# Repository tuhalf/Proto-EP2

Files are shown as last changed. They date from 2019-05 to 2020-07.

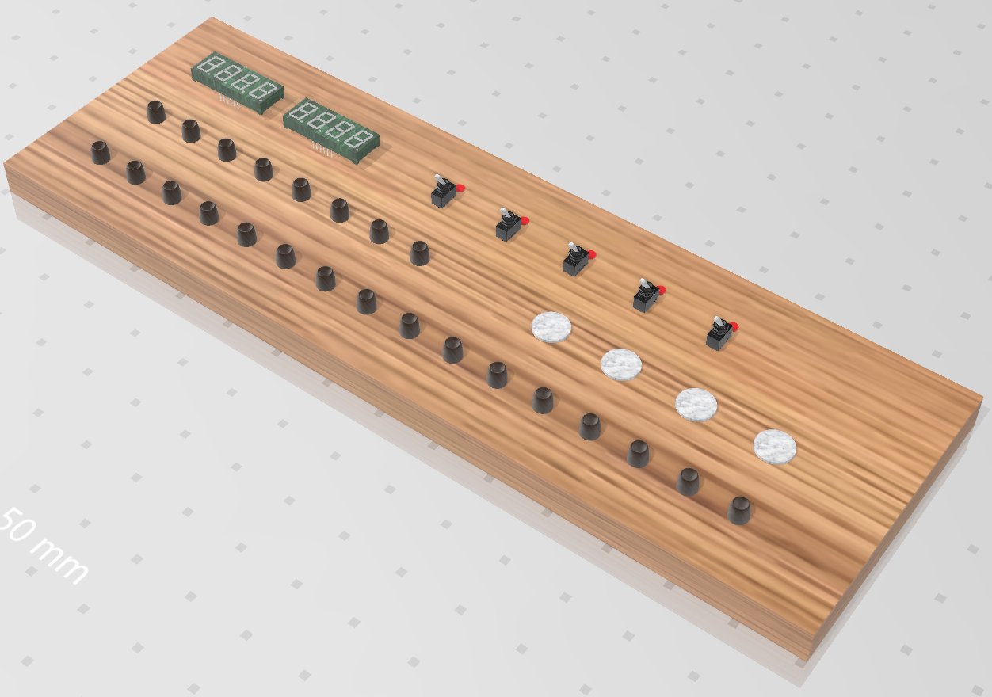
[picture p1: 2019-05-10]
Screenshots/frontPanel.png

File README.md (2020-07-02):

# Proto - Educational Pupose 8-Bit Processor
Made for students, teachers, and any soul who wants to understand how a CPU works. Open Source.

Instruction Sets
 I : Instruction 
{ }: Register 
[ ]: Adress
( ): Condition - Based on registers A and B, takes parameters > or =
______________________________________________________________________
ADD [X]
	Add two numbers that are in A and B registers and write it to X address

SUB [X]- Subtract
	Subtract A from B and write it to X address 

LOAD {X} 
	Load data from next adress to X register 

STORE [X]
	Store data form register A to X adress in RAM 

LWJ {X} [Y] - Load With Jump
	Load data from Y adress to X register

JUMP [X]
	Jump to X adress in RAM

CJ (X) [Y] - Conditional Jump (Carry or Zero)
	If X condition is TRUE, jump to Y adress in RAM
  
LSCR [X] [Y]
	Loads the data stored in X address from RAM to Y address from GPU (Each bit is one pixel)
  
LSCR {X} [Y]
	Loads the data stored in X register to Y address from GPU (Each bit is one pixel)
  
LPNC [X]
	Starts loading the punch card starting from X address
  
HLT
	Halts the system

------------------------------------------------------------------------------------------------------------------------------------

Microcode Explained
bits
0nnnn00000nn00__
1000000000000000    HLT - 1
0100000000000000    REG_READ - 2
0010000000000000    AWRITE - 3	(Connected to ALUWRITE and Or'ed with AWRITE because there are not enough controll bits)
0001000000000000    FL - 4
0000100000000000    ALUWRITE - 5(Connected to RAM_WRITE and Or'ed with AWRITE because there are not enough controll bits)
0000010000000000    ALUSUB - 6
0000001000000000    PC_LE - 7
0000000100000000    PC_LRS - 8
0000000010000000    RAM_LRS - 9
0000000001000000    SLC_ADDR - 10
0000000000100000    RAM_OUT - 11
0000000000010000    INSTREAD - 12
0000000000001000    COUNT - 13
0000000000000100    RAM_AS - 14
0000000000000010    --
0000000000000001    --
01111000 00110000				00------000
----JUMP [X]---- (N-------,XXXXXXXX,XXXXXXXX)	nn100000                        
COUNT						00100000000 - 01111000 00111000
PC_LRS || RAM_OUT				00100000100 - 01111001 00010000
COUNT						00100000010 - 01111000 00111000	
RAM_OUT || PC_LE			        00100000110 - 01111010 00010000
RAM_OUT || INSTREAD				00100000001 - 01111000 00000000
----------------
----LOAD {X}---- (X-------)			                nn010000    
COUNT                                           00010000000 - 01111000 00111000
RAM_OUT || REG_READ                             00010000100 - 00111000 00010000
COUNT                                           00010000010 - 01111000 00111000
RAM_OUT || INSTREAD                             00010000110 - 01111000 00000000
----------------
----ADD [X]---- (N-------,XXXXXXXX,XXXXXXXX)    nn110000
COUNT || RAM_OUT || RAM_LRS || SLC_ADDR         00110000000 - 01111000 11011000
COUNT || RAM_OUT || SLC_ADDR                    00110000100 - 01111000 01011000
RAM_AS || ALUWRITE                              00110000010 - 01110000 00110100
RAM_OUT || INSTREAD                             00110000110 - 01111000 00000000
----------------
----SUB [X]---- (N-------,XXXXXXXX,XXXXXXXX)    nn001000
COUNT || RAM_OUT || RAM_LRS || SLC_ADDR         00001000000 - 01111000 11011000
COUNT || RAM_OUT || SLC_ADDR                    00001000100 - 01111000 01011000
RAM_AS || ALUSUB || ALUWRITE                    00001000010 - 01110100 00110100
RAM_OUT || INSTREAD                             00001000110 - 01111000 00000000
----------------
----STORE [X]---- (N-------,XXXXXXXX,XXXXXXXX)  nn101000
COUNT || RAM_OUT || RAM_LRS || SLC_ADDR         00101000000 - 01111000 11011000
COUNT || RAM_OUT || SLC_ADDR                    00101000100 - 01111000 01011000
RAM_AS || AWRITE                                00101000010 - 01011000 00110100
RAM_OUT || INSTREAD                             00101000110 - 01111000 00000000
-----------------
----LWJ {X} [Y]---- (X-------,YYYYYYYY,YYYYYYYY)nn111000
COUNT || RAM_OUT || RAM_LRS || SLC_ADDR         00111000000 - 01111000 11011000
COUNT || RAM_OUT || SLC_ADDR                    00111000100 - 01111000 01011000
RAM_AS || RAM_OUT || REG_READ                   00111000010 - 00111000 00010100
RAM_OUT || INSTREAD                             00111000110 - 01111000 00000000
-------------------
----CJ (ZERO) [Y]-- (N-1-----,XXXXXXXX,XXXXXXXX)nn001100
COUNT || FL                                     00001100000 - 01101000 00111000
01OOOOOO[PC_LRS || RAM_OUT                      01001100100 - 01111001 00010000
COUNT || RAM_OUT || PC_LE                       01001100010 - 01111010 00011000
RAM_OUT || INSTREAD]                            01001100110 - 01111000 00000000
COUNT                                           00001100100 - 01111000 00111000
COUNT || RAM_OUT || INSTREAD                    00001100010 - 01111000 00001000
---------------------
---CJ (CARRY) [Y]-- (N-1-----,XXXXXXXX,XXXXXXXX)nn100100
COUNT || FL                                     00100100000 - 01101000 00111000
10OOOOOO[PC_LRS || RAM_OUT                      10100100100 - 01111001 00010000
COUNT || RAM_OUT || PC_LE                       10100100010 - 01111010 00011000
RAM_OUT || INSTREAD]                            10100100110 - 01111000 00000000
COUNT                                           00100100100 - 01111000 00111000
COUNT || RAM_OUT || INSTREAD                    00100100010 - 01111000 00001000
---------------------
----HLT----                                     nn111111
HLT                                             00111111000 - 11111000 00110000
-----------

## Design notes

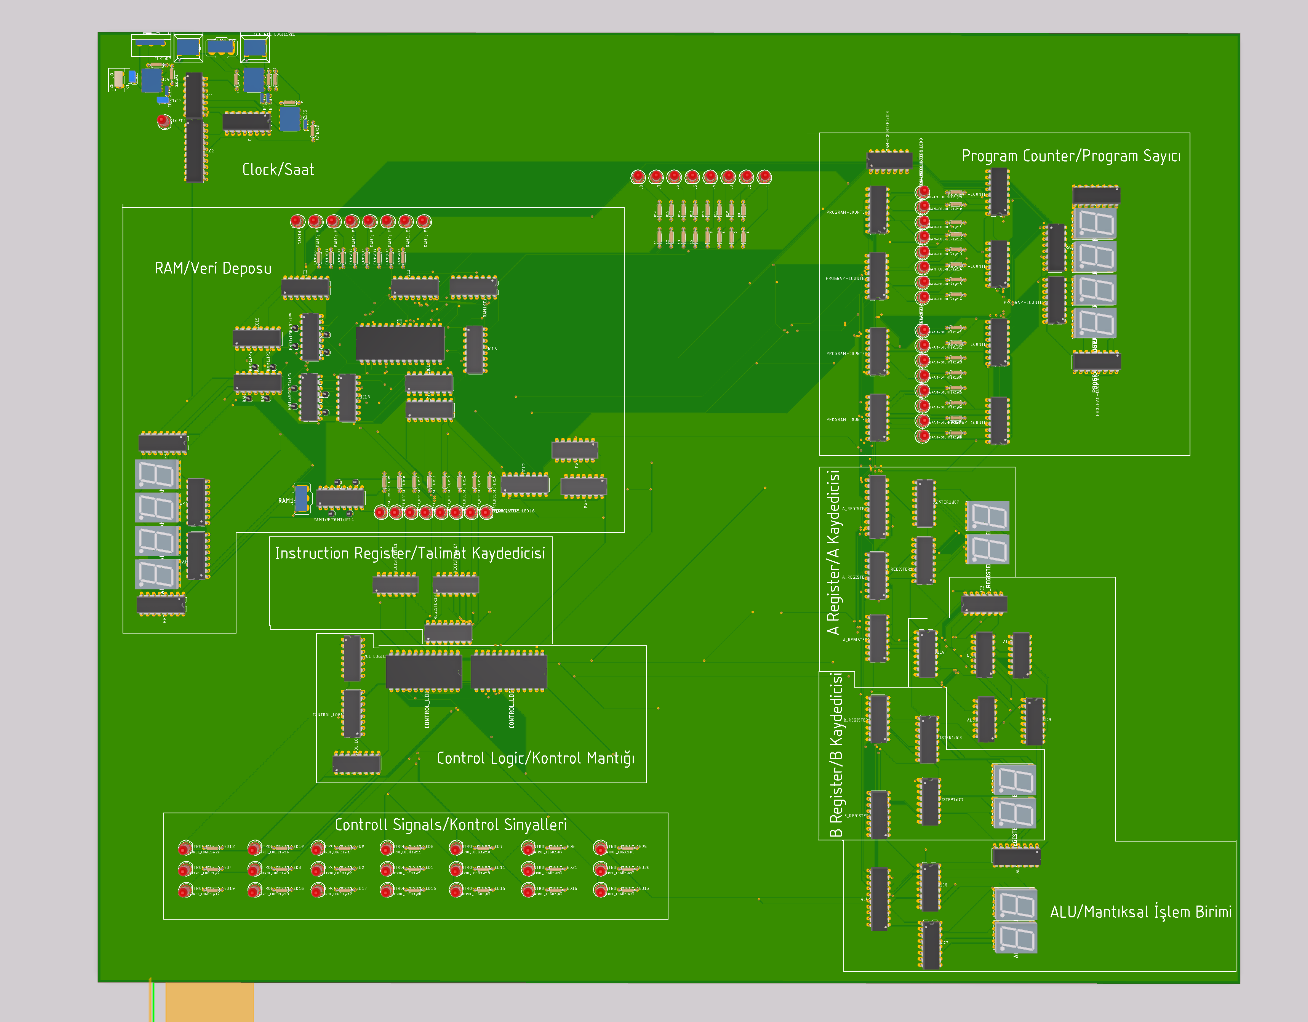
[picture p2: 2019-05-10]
Screenshots/pcb2.png

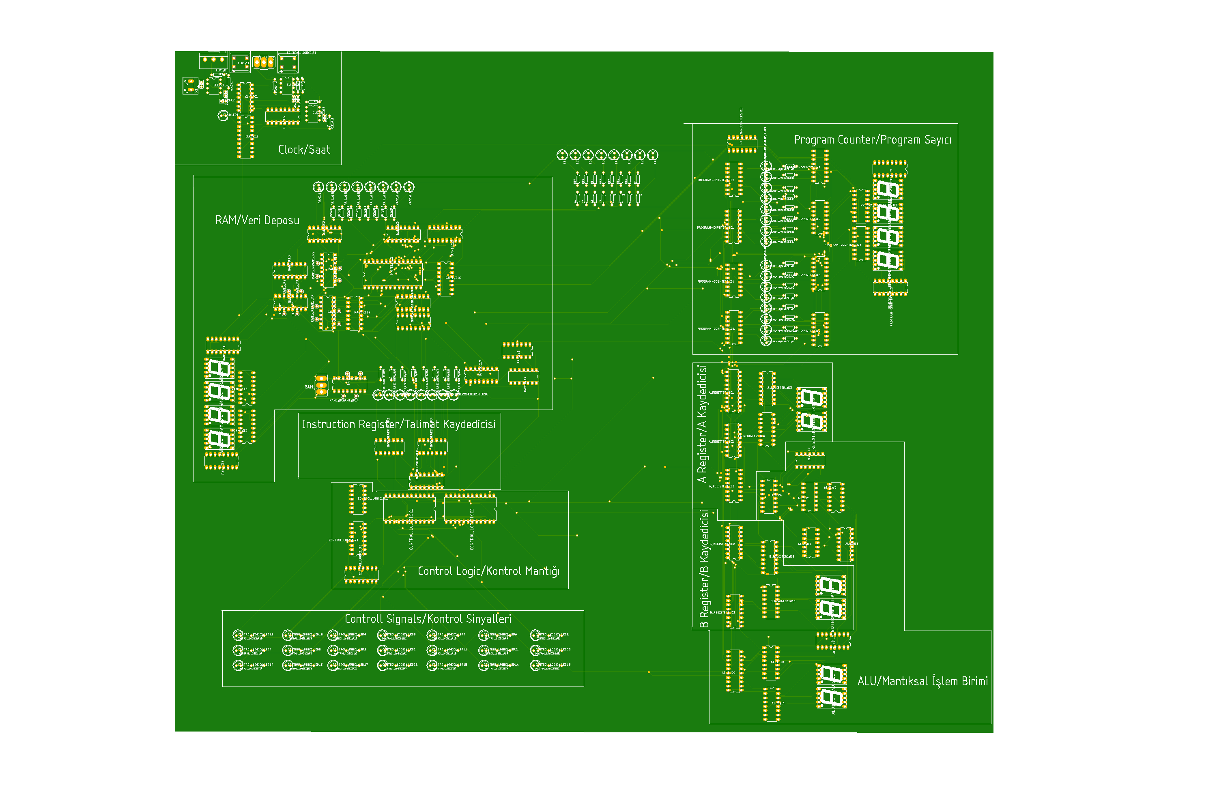
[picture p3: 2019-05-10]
Screenshots/pcbTop.png

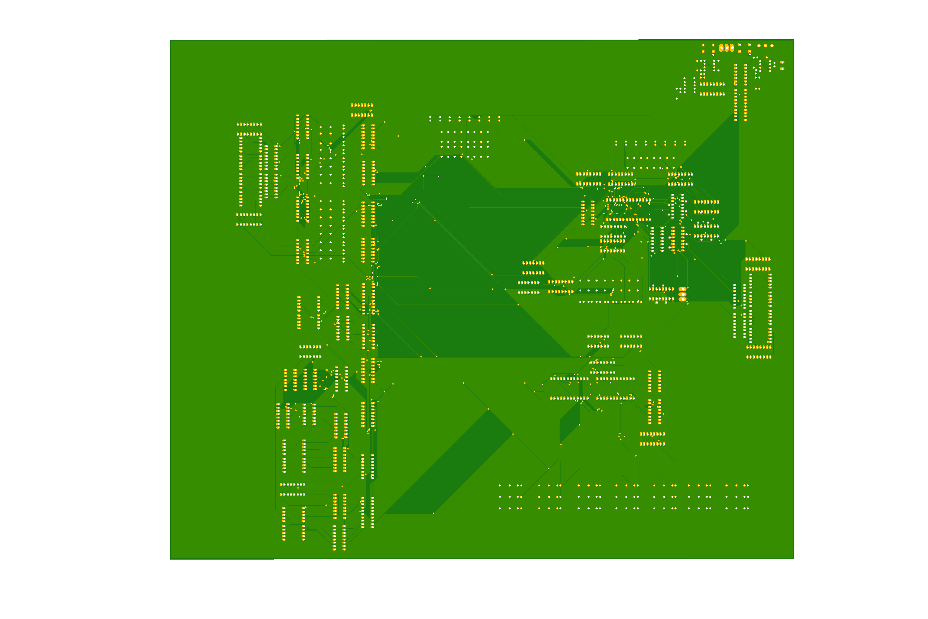
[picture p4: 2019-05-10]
Screenshots/pcbBottom.png

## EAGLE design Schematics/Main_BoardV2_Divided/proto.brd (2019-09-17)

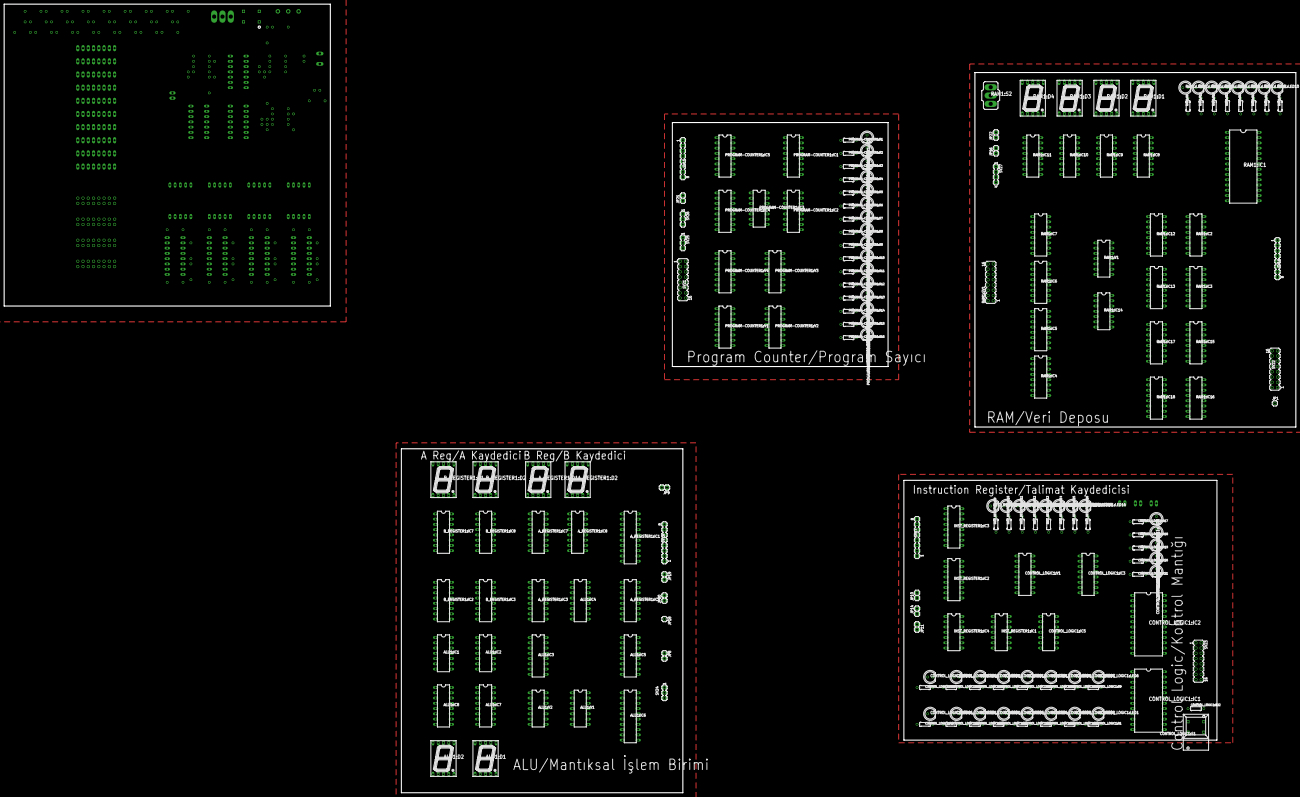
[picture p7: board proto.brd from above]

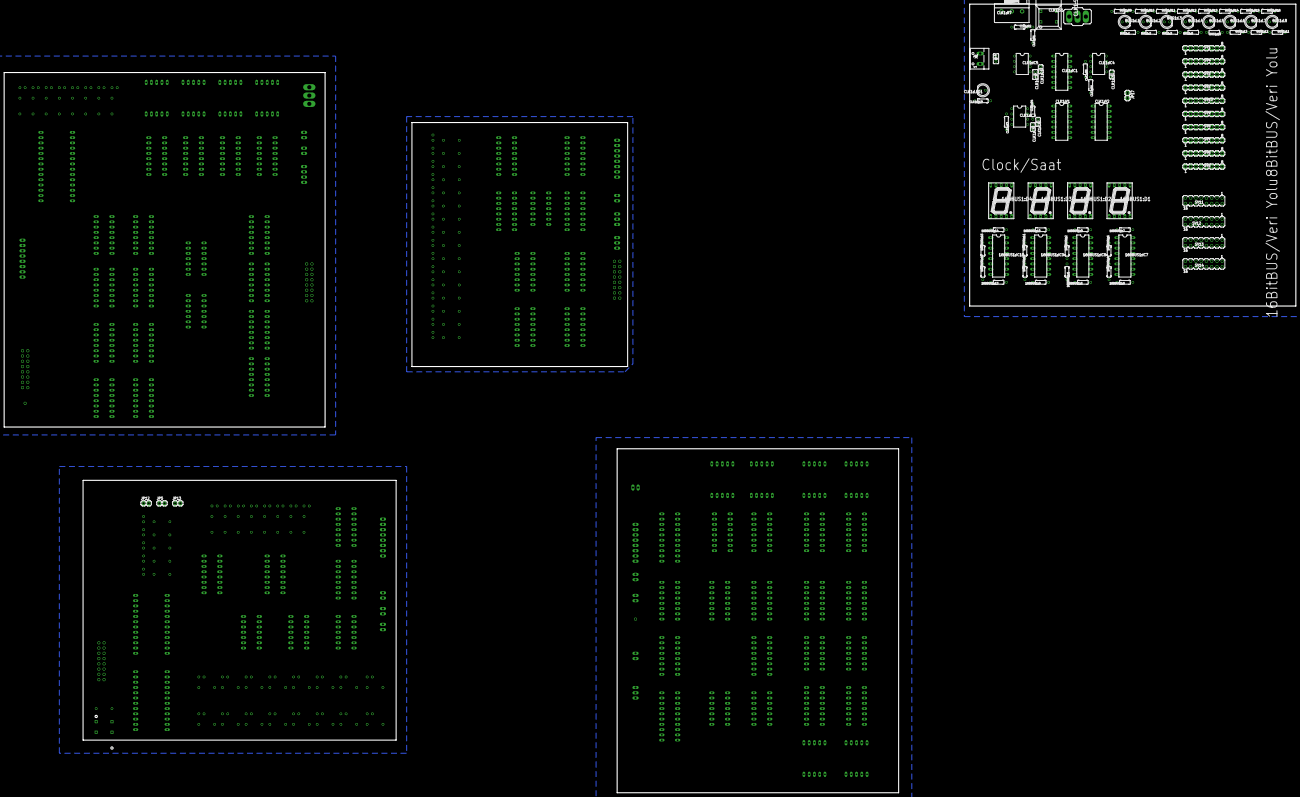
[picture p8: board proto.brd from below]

Board: 2 copper layers, 623.5 x 380.7 mm, 289 parts (90 on the bottom side), 422 nets, no tracks yet.

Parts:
16BBUS1:1, 16BBUS1:2, 16BBUS1:3, 16BBUS1:4, 16BBUS1:5, 16BBUS1:6, 16BBUS1:7, 16BBUS1:8, 16BBUS1:9, 16BBUS1:10, 16BBUS1:11, 16BBUS1:12, 16BBUS1:13, 16BBUS1:14, 16BBUS1:15, 16BBUS1:16: 10k; 0204/7
16BBUS1:D1, 16BBUS1:D2, 16BBUS1:D3, 16BBUS1:D4: 7SEG-13
16BBUS1:IC7, 16BBUS1:IC8, 16BBUS1:IC9, 16BBUS1:IC10: 74LS47N; DIL16
ALU1:D1, ALU1:D2: 7SEG-13
ALU1:IC1, ALU1:IC2: 74LS86N; DIL14
ALU1:IC3, ALU1:IC4: 74AC283N; DIL16
ALU1:IC5: 74HC173N; DIL16
ALU1:IC6: 74ACT245N; DIL20
ALU1:IC7, ALU1:IC8: 74LS47N; DIL16
ALU1:V1: 744002N; DIL14
ALU1:V2: 7409N; DIL14
A_REGISTER1:D1, A_REGISTER1:D2: 7SEG-13
A_REGISTER1:IC1: 74ACT245N; DIL20
A_REGISTER1:IC2, A_REGISTER1:IC3: 74HC173N; DIL16
A_REGISTER1:IC7, A_REGISTER1:IC8: 74LS47N; DIL16
BUS1:1, BUS1:2, BUS1:3, BUS1:5, BUS1:11, BUS1:12, BUS1:13, BUS1:15: 10k; 0204/7
BUS1:L1, BUS1:L2, BUS1:L3, BUS1:L4, BUS1:L5, BUS1:L6, BUS1:L7, BUS1:L8: LED5MM
BUS1:R9, BUS1:R10, BUS1:R11, BUS1:R12, BUS1:R13, BUS1:R14, BUS1:R15, BUS1:R16: 220; 0204/7
B_REGISTER1:D1, B_REGISTER1:D2: 7SEG-13
B_REGISTER1:IC2, B_REGISTER1:IC3: 74HC173N; DIL16
B_REGISTER1:IC7, B_REGISTER1:IC8: 74LS47N; DIL16
C1: 330uf; C025-025X050
CLK1:C1: 1uf; C025-024X044
CLK1:C2: 0.01uF; C025-025X050
CLK1:C3, CLK1:C5: 0.01uF; C025-024X044
CLK1:C4: 0.1uf; C025-024X044
CLK1:IC1: 74ALS09N; DIL14
CLK1:IC3, CLK1:IC4, CLK1:IC5: LM555N; DIL08
CLK1:LED1: LED5MM
CLK1:R1, CLK1:R2, CLK1:R3, CLK1:R4, CLK1:R5, CLK1:R6: 1k; 0204/7
CLK1:R7: 3RP/1610N
CLK1:R13: 220; 0204/7
CLK1:S1: 5501
CLK1:S2: 320-916
CLK1:V1: 7404N; DIL14
CLK1:V2: 7432N; DIL14
CONTROL_LOGIC1:IC1, CONTROL_LOGIC1:IC2: DIL24
CONTROL_LOGIC1:IC3: 74AC138N; DIL16
CONTROL_LOGIC1:IC5: 74AC00N; DIL14
CONTROL_LOGIC1:LED1, CONTROL_LOGIC1:LED2, CONTROL_LOGIC1:LED3, CONTROL_LOGIC1:LED4, CONTROL_LOGIC1:LED5, CONTROL_LOGIC1:LED6, CONTROL_LOGIC1:LED7, CONTROL_LOGIC1:LED8, CONTROL_LOGIC1:LED9, CONTROL_LOGIC1:LED10, CONTROL_LOGIC1:LED11, CONTROL_LOGIC1:LED12, CONTROL_LOGIC1:LED13, CONTROL_LOGIC1:LED14, CONTROL_LOGIC1:LED15, CONTROL_LOGIC1:LED16, CONTROL_LOGIC1:LED17, CONTROL_LOGIC1:LED18, CONTROL_LOGIC1:LED19, CONTROL_LOGIC1:LED20, CONTROL_LOGIC1:LED21: LED5MM
CONTROL_LOGIC1:R1, CONTROL_LOGIC1:R2, CONTROL_LOGIC1:R3, CONTROL_LOGIC1:R4, CONTROL_LOGIC1:R5, CONTROL_LOGIC1:R6, CONTROL_LOGIC1:R7, CONTROL_LOGIC1:R8, CONTROL_LOGIC1:R9, CONTROL_LOGIC1:R10, CONTROL_LOGIC1:R11, CONTROL_LOGIC1:R12, CONTROL_LOGIC1:R13, CONTROL_LOGIC1:R14, CONTROL_LOGIC1:R15, CONTROL_LOGIC1:R16, CONTROL_LOGIC1:R17, CONTROL_LOGIC1:R18, CONTROL_LOGIC1:R19, CONTROL_LOGIC1:R20, CONTROL_LOGIC1:R21, CONTROL_LOGIC1:R22: 220; 0204/7
CONTROL_LOGIC1:S1: 5501
CONTROL_LOGIC1:V1: 74161N; DIL16
INST_REGISTER1:IC1: 74ALS09N; DIL14
INST_REGISTER1:IC2, INST_REGISTER1:IC3: 74HC173N; DIL16
INST_REGISTER1:IC4: 74AC04N; DIL14
INST_REGISTER1:LED9, INST_REGISTER1:LED10, INST_REGISTER1:LED11, INST_REGISTER1:LED12, INST_REGISTER1:LED13, INST_REGISTER1:LED14, INST_REGISTER1:LED15, INST_REGISTER1:LED16: LED5MM
INST_REGISTER1:R9, INST_REGISTER1:R10, INST_REGISTER1:R11, INST_REGISTER1:R12, INST_REGISTER1:R13, INST_REGISTER1:R14, INST_REGISTER1:R15, INST_REGISTER1:R16: 220; 0204/7
JP1, JP18: 1X01
JP5, JP8, JP9, JP10, JP11, JP12, JP13, JP14, JP16, JP17, JP19, JP20, JP21, JP22: 1X02
PROGRAM-COUNTER1:IC1, PROGRAM-COUNTER1:IC2, PROGRAM-COUNTER1:IC4, PROGRAM-COUNTER1:IC5: 74HC173N; DIL16
PROGRAM-COUNTER1:IC3: 74AC04N; DIL14
PROGRAM-COUNTER1:LED1, PROGRAM-COUNTER1:LED2, PROGRAM-COUNTER1:LED3, PROGRAM-COUNTER1:LED4, PROGRAM-COUNTER1:LED5, PROGRAM-COUNTER1:LED6, PROGRAM-COUNTER1:LED7, PROGRAM-COUNTER1:LED8, PROGRAM-COUNTER1:LED9, PROGRAM-COUNTER1:LED10, PROGRAM-COUNTER1:LED11, PROGRAM-COUNTER1:LED12, PROGRAM-COUNTER1:LED13, PROGRAM-COUNTER1:LED14, PROGRAM-COUNTER1:LED15, PROGRAM-COUNTER1:LED16: LED5MM
PROGRAM-COUNTER1:R1, PROGRAM-COUNTER1:R2, PROGRAM-COUNTER1:R3, PROGRAM-COUNTER1:R4, PROGRAM-COUNTER1:R5, PROGRAM-COUNTER1:R6, PROGRAM-COUNTER1:R7, PROGRAM-COUNTER1:R8, PROGRAM-COUNTER1:R9, PROGRAM-COUNTER1:R10, PROGRAM-COUNTER1:R11, PROGRAM-COUNTER1:R12, PROGRAM-COUNTER1:R13, PROGRAM-COUNTER1:R14, PROGRAM-COUNTER1:R15, PROGRAM-COUNTER1:R16: 220; 0204/7
PROGRAM-COUNTER1:V1, PROGRAM-COUNTER1:V2, PROGRAM-COUNTER1:V3, PROGRAM-COUNTER1:V4: 74161N; DIL16
RAM1:D1, RAM1:D2, RAM1:D3, RAM1:D4: 7SEG-13
RAM1:IC1: CY62256LL-PC; DIL28-6
RAM1:IC2, RAM1:IC3, RAM1:IC12, RAM1:IC13: 74HC173N; DIL16
RAM1:IC4, RAM1:IC5, RAM1:IC6, RAM1:IC7, RAM1:IC15, RAM1:IC16, RAM1:IC17, RAM1:IC18: 74AC157N; DIL16
RAM1:IC8, RAM1:IC9, RAM1:IC10, RAM1:IC11: 74LS47N; DIL16
RAM1:IC14: 74AC04N; DIL14
RAM1:LED9, RAM1:LED10, RAM1:LED11, RAM1:LED12, RAM1:LED13, RAM1:LED14, RAM1:LED15, RAM1:LED16: LED5MM
RAM1:R9, RAM1:R10, RAM1:R11, RAM1:R12, RAM1:R13, RAM1:R14, RAM1:R15, RAM1:R16: 220; 0204/7
RAM1:S2: 320-916
RAM1:SV1: MA08-2
RAM1:V1: 7409N; DIL14
SV1, SV2, SV3, SV4, SV5, SV6, SV7, SV8, SV9, SV10, SV15, SV16, SV17, SV18: MA08-1
SV11, SV12, SV13, SV14, SV21, SV22, SV23: MA08-2
SV24, SV25, SV26: MA03-1
SV27: MA04-1
X1: W237-102

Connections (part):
8B_1: ALU1:IC6.18, A_REGISTER1:IC1.18, A_REGISTER1:IC3.14, B_REGISTER1:IC3.14, INST_REGISTER1:IC3.14, PROGRAM-COUNTER1:IC1.14, PROGRAM-COUNTER1:IC5.14, RAM1:IC1.11, RAM1:IC2.14, RAM1:IC12.14, RAM1:LED9.A, SV15.1, SV16.1, SV17.8, SV18.8
8B_2: ALU1:IC6.17, A_REGISTER1:IC1.17, A_REGISTER1:IC3.13, B_REGISTER1:IC3.13, INST_REGISTER1:IC3.13, PROGRAM-COUNTER1:IC1.13, PROGRAM-COUNTER1:IC5.13, RAM1:IC1.12, RAM1:IC2.13, RAM1:IC12.13, RAM1:LED10.A, SV15.2, SV16.2, SV17.7, SV18.7
8B_3: ALU1:IC6.16, A_REGISTER1:IC1.16, A_REGISTER1:IC3.12, B_REGISTER1:IC3.12, INST_REGISTER1:IC3.12, PROGRAM-COUNTER1:IC1.12, PROGRAM-COUNTER1:IC5.12, RAM1:IC1.13, RAM1:IC2.12, RAM1:IC12.12, RAM1:LED11.A, SV15.3, SV16.3, SV17.6, SV18.6
8B_4: ALU1:IC6.15, A_REGISTER1:IC1.15, A_REGISTER1:IC3.11, B_REGISTER1:IC3.11, INST_REGISTER1:IC3.11, PROGRAM-COUNTER1:IC1.11, PROGRAM-COUNTER1:IC5.11, RAM1:IC1.15, RAM1:IC2.11, RAM1:IC12.11, RAM1:LED12.A, SV15.4, SV16.4, SV17.5, SV18.5
8B_5: ALU1:IC6.14, A_REGISTER1:IC1.14, A_REGISTER1:IC2.14, INST_REGISTER1:IC2.14, PROGRAM-COUNTER1:IC2.14, PROGRAM-COUNTER1:IC4.14, RAM1:IC1.16, RAM1:IC3.14, RAM1:IC13.14, RAM1:LED13.A, SV15.5, SV16.5, SV17.4, SV18.4
8B_6: ALU1:IC6.13, A_REGISTER1:IC1.13, A_REGISTER1:IC2.13, INST_REGISTER1:IC2.13, PROGRAM-COUNTER1:IC2.13, PROGRAM-COUNTER1:IC4.13, RAM1:IC1.17, RAM1:IC3.13, RAM1:IC13.13, RAM1:LED14.A, SV15.6, SV16.6, SV17.3, SV18.3
8B_7: ALU1:IC6.12, A_REGISTER1:IC1.12, A_REGISTER1:IC2.12, INST_REGISTER1:IC2.12, PROGRAM-COUNTER1:IC2.12, PROGRAM-COUNTER1:IC4.12, RAM1:IC1.18, RAM1:IC3.12, RAM1:IC13.12, RAM1:LED15.A, SV15.7, SV16.7, SV17.2, SV18.2
8B_8: ALU1:IC6.11, A_REGISTER1:IC1.11, A_REGISTER1:IC2.11, INST_REGISTER1:IC2.11, PROGRAM-COUNTER1:IC2.11, PROGRAM-COUNTER1:IC4.11, RAM1:IC1.19, RAM1:IC3.11, RAM1:IC13.11, RAM1:LED16.A, SV15.8, SV16.8, SV17.1, SV18.1
16BBUS1:N$9: 16BBUS1:D1.7, 16BBUS1:IC7.13
16BBUS1:N$10: 16BBUS1:D1.6, 16BBUS1:IC7.12
16BBUS1:N$11: 16BBUS1:D1.4, 16BBUS1:IC7.11
16BBUS1:N$12: 16BBUS1:D1.2, 16BBUS1:IC7.10
16BBUS1:N$13: 16BBUS1:D1.1, 16BBUS1:IC7.9
16BBUS1:N$14: 16BBUS1:D1.9, 16BBUS1:IC7.15
16BBUS1:N$15: 16BBUS1:D1.10, 16BBUS1:IC7.14
16BBUS1:N$16: 16BBUS1:D2.7, 16BBUS1:IC8.13
16BBUS1:N$17: 16BBUS1:D4.7, 16BBUS1:IC10.13
16BBUS1:N$18: 16BBUS1:D4.6, 16BBUS1:IC10.12
16BBUS1:N$19: 16BBUS1:D4.4, 16BBUS1:IC10.11
16BBUS1:N$20: 16BBUS1:D4.2, 16BBUS1:IC10.10
16BBUS1:N$21: 16BBUS1:D2.6, 16BBUS1:IC8.12
16BBUS1:N$22: 16BBUS1:D2.4, 16BBUS1:IC8.11
16BBUS1:N$23: 16BBUS1:D2.2, 16BBUS1:IC8.10
16BBUS1:N$24: 16BBUS1:D2.1, 16BBUS1:IC8.9
16BBUS1:N$25: 16BBUS1:D4.1, 16BBUS1:IC10.9
16BBUS1:N$26: 16BBUS1:D4.9, 16BBUS1:IC10.15
16BBUS1:N$27: 16BBUS1:D4.10, 16BBUS1:IC10.14
16BBUS1:N$29: 16BBUS1:D2.9, 16BBUS1:IC8.15
16BBUS1:N$30: 16BBUS1:D2.10, 16BBUS1:IC8.14
16BBUS1:N$31: 16BBUS1:D3.7, 16BBUS1:IC9.13
16BBUS1:N$32: 16BBUS1:D3.6, 16BBUS1:IC9.12
16BBUS1:N$33: 16BBUS1:D3.4, 16BBUS1:IC9.11
16BBUS1:N$34: 16BBUS1:D3.2, 16BBUS1:IC9.10
16BBUS1:N$35: 16BBUS1:D3.1, 16BBUS1:IC9.9
16BBUS1:N$36: 16BBUS1:D3.9, 16BBUS1:IC9.15
16BBUS1:N$37: 16BBUS1:D3.10, 16BBUS1:IC9.14
16BBUS1:VCC: 16BBUS1:D1.3, 16BBUS1:D1.5, 16BBUS1:D1.8, 16BBUS1:D2.3, 16BBUS1:D2.5, 16BBUS1:D2.8, 16BBUS1:D3.3, 16BBUS1:D3.5, 16BBUS1:D3.8, 16BBUS1:D4.3, 16BBUS1:D4.5, 16BBUS1:D4.8, 16BBUS1:IC7.16, 16BBUS1:IC8.16, 16BBUS1:IC9.16, 16BBUS1:IC10.16
ALU1:+UB: ALU1:V1.14, ALU1:V2.14
ALU1:-UB: ALU1:V1.7, ALU1:V2.7
ALU1:A_9: ALU1:IC4.4, ALU1:IC6.9, ALU1:IC8.7, ALU1:V1.9
ALU1:A_10: ALU1:IC4.1, ALU1:IC6.8, ALU1:IC8.1, ALU1:V1.10
ALU1:A_11: ALU1:IC4.10, ALU1:IC6.6, ALU1:IC8.6, ALU1:V1.12
ALU1:A_12: ALU1:IC4.13, ALU1:IC6.7, ALU1:IC8.2, ALU1:V1.11
ALU1:A_13: ALU1:IC3.4, ALU1:IC6.5, ALU1:IC7.7, ALU1:V1.2
ALU1:A_14: ALU1:IC3.1, ALU1:IC6.4, ALU1:IC7.1, ALU1:V1.3
ALU1:A_15: ALU1:IC3.13, ALU1:IC6.3, ALU1:IC7.2, ALU1:V1.4
ALU1:A_16: ALU1:IC3.10, ALU1:IC6.2, ALU1:IC7.6, ALU1:V1.5
ALU1:N$1: ALU1:IC2.11, ALU1:IC4.6
ALU1:N$2: ALU1:IC2.8, ALU1:IC4.2
ALU1:N$3: ALU1:IC2.6, ALU1:IC4.15
ALU1:N$4: ALU1:IC2.3, ALU1:IC4.11
ALU1:N$5: ALU1:IC1.11, ALU1:IC3.6
ALU1:N$6: ALU1:IC1.6, ALU1:IC3.15
ALU1:N$7: ALU1:IC1.8, ALU1:IC3.2
ALU1:N$8: ALU1:IC1.3, ALU1:IC3.11
ALU1:N$9: ALU1:IC3.7, ALU1:IC4.9
ALU1:N$10: ALU1:D1.7, ALU1:IC7.13
ALU1:N$11: ALU1:D1.6, ALU1:IC7.12
ALU1:N$12: ALU1:D1.4, ALU1:IC7.11
ALU1:N$13: ALU1:D1.2, ALU1:IC7.10
ALU1:N$14: ALU1:D1.1, ALU1:IC7.9
ALU1:N$15: ALU1:D1.9, ALU1:IC7.15
ALU1:N$16: ALU1:D1.10, ALU1:IC7.14
ALU1:N$17: ALU1:D2.7, ALU1:IC8.13
ALU1:N$18: ALU1:V1.1, ALU1:V2.2
ALU1:N$19: ALU1:V1.13, ALU1:V2.1
ALU1:N$20: ALU1:IC5.14, ALU1:V2.3
ALU1:N$21: ALU1:D2.6, ALU1:IC8.12
ALU1:N$22: ALU1:D2.4, ALU1:IC8.11
ALU1:N$23: ALU1:D2.2, ALU1:IC8.10
ALU1:N$24: ALU1:D2.1, ALU1:IC8.9
ALU1:N$25: ALU1:IC3.9, ALU1:IC5.13
ALU1:N$29: ALU1:D2.9, ALU1:IC8.15
ALU1:N$30: ALU1:D2.10, ALU1:IC8.14
ALUSUB: CONTROL_LOGIC1:IC1.15, CONTROL_LOGIC1:LED3.A, SV23.11
A_REGISTER1:N$9: A_REGISTER1:D1.7, A_REGISTER1:IC7.13
A_REGISTER1:N$10: A_REGISTER1:D1.6, A_REGISTER1:IC7.12
A_REGISTER1:N$11: A_REGISTER1:D1.4, A_REGISTER1:IC7.11
A_REGISTER1:N$12: A_REGISTER1:D1.2, A_REGISTER1:IC7.10
A_REGISTER1:N$13: A_REGISTER1:D1.1, A_REGISTER1:IC7.9
A_REGISTER1:N$14: A_REGISTER1:D1.9, A_REGISTER1:IC7.15
A_REGISTER1:N$15: A_REGISTER1:D1.10, A_REGISTER1:IC7.14
A_REGISTER1:N$16: A_REGISTER1:D2.7, A_REGISTER1:IC8.13
A_REGISTER1:N$21: A_REGISTER1:D2.6, A_REGISTER1:IC8.12
A_REGISTER1:N$22: A_REGISTER1:D2.4, A_REGISTER1:IC8.11
A_REGISTER1:N$23: A_REGISTER1:D2.2, A_REGISTER1:IC8.10
A_REGISTER1:N$24: A_REGISTER1:D2.1, A_REGISTER1:IC8.9
A_REGISTER1:N$29: A_REGISTER1:D2.9, A_REGISTER1:IC8.15
A_REGISTER1:N$30: A_REGISTER1:D2.10, A_REGISTER1:IC8.14
BUS1:N$38: BUS1:L1.K, BUS1:R9.2
BUS1:N$39: BUS1:L2.K, BUS1:R10.2
BUS1:N$40: BUS1:L3.K, BUS1:R11.2
BUS1:N$41: BUS1:L4.K, BUS1:R12.2
BUS1:N$42: BUS1:L5.K, BUS1:R13.2
BUS1:N$43: BUS1:L6.K, BUS1:R14.2
BUS1:N$44: BUS1:L7.K, BUS1:R15.2
BUS1:N$45: BUS1:L8.K, BUS1:R16.2
B_REGISTER1:N$9: B_REGISTER1:D1.7, B_REGISTER1:IC7.13
B_REGISTER1:N$10: B_REGISTER1:D1.6, B_REGISTER1:IC7.12
B_REGISTER1:N$11: B_REGISTER1:D1.4, B_REGISTER1:IC7.11
B_REGISTER1:N$12: B_REGISTER1:D1.2, B_REGISTER1:IC7.10
B_REGISTER1:N$13: B_REGISTER1:D1.1, B_REGISTER1:IC7.9
B_REGISTER1:N$14: B_REGISTER1:D1.9, B_REGISTER1:IC7.15
B_REGISTER1:N$15: B_REGISTER1:D1.10, B_REGISTER1:IC7.14
B_REGISTER1:N$16: B_REGISTER1:D2.7, B_REGISTER1:IC8.13
B_REGISTER1:N$21: B_REGISTER1:D2.6, B_REGISTER1:IC8.12
B_REGISTER1:N$22: B_REGISTER1:D2.4, B_REGISTER1:IC8.11
B_REGISTER1:N$23: B_REGISTER1:D2.2, B_REGISTER1:IC8.10
B_REGISTER1:N$24: B_REGISTER1:D2.1, B_REGISTER1:IC8.9
B_REGISTER1:N$29: B_REGISTER1:D2.9, B_REGISTER1:IC8.15
B_REGISTER1:N$30: B_REGISTER1:D2.10, B_REGISTER1:IC8.14
B_REGISTER1:VCC: B_REGISTER1:IC2.16, B_REGISTER1:IC3.16, B_REGISTER1:IC7.16, B_REGISTER1:IC8.16
CF: ALU1:IC5.4, CONTROL_LOGIC1:IC1.7, CONTROL_LOGIC1:IC2.7, JP8.2, JP12.2
CLK: ALU1:IC5.7, A_REGISTER1:IC2.7, A_REGISTER1:IC3.7, B_REGISTER1:IC2.7, B_REGISTER1:IC3.7, CLK1:IC1.8, CLK1:LED1.A, CONTROL_LOGIC1:V1.2, INST_REGISTER1:IC2.7, INST_REGISTER1:IC3.7, JP14.1, JP16.1, JP17.1, JP20.1, PROGRAM-COUNTER1:IC1.7, PROGRAM-COUNTER1:IC2.7, PROGRAM-COUNTER1:IC4.7, PROGRAM-COUNTER1:IC5.7, PROGRAM-COUNTER1:V1.2, PROGRAM-COUNTER1:V2.2, PROGRAM-COUNTER1:V3.2, PROGRAM-COUNTER1:V4.2, RAM1:IC2.7, RAM1:IC3.7, RAM1:IC12.7, RAM1:IC13.7, SV25.3
CLK1:+UB: CLK1:V1.14, CLK1:V2.14
CLK1:-UB: CLK1:V1.7, CLK1:V2.7
CLK1:ACLK: CLK1:IC1.1, CLK1:IC5.3
CLK1:AMS: CLK1:IC1.2, CLK1:IC4.3, CLK1:V1.1
CLK1:MCLK: CLK1:IC1.5, CLK1:IC3.3
CLK1:N$1: CLK1:IC4.2, CLK1:R5.1, CLK1:S2.1
CLK1:N$2: CLK1:IC3.2, CLK1:R3.1, CLK1:S1.NO
CLK1:N$3: CLK1:IC4.4, CLK1:R6.1, CLK1:S2.3
CLK1:N$4: CLK1:C3.1, CLK1:IC3.5
CLK1:N$5: CLK1:C5.1, CLK1:IC4.5
CLK1:N$6: CLK1:LED1.K, CLK1:R13.2
CLK1:N$7: CLK1:C4.1, CLK1:IC3.6, CLK1:IC3.7, CLK1:R4.1
CLK1:N$8: CLK1:IC1.10, CLK1:V1.4
CLK1:N$9: CLK1:IC5.7, CLK1:R1.1, CLK1:R2.2
CLK1:N$10: CLK1:C2.1, CLK1:IC5.5
CLK1:N$11: CLK1:R2.1, CLK1:R7.2
CLK1:N$12: CLK1:IC1.6, CLK1:V2.2
CLK1:N$13: CLK1:IC1.3, CLK1:V2.1
CLK1:N$14: CLK1:IC1.9, CLK1:V2.3
CLK1:N$17: CLK1:IC1.4, CLK1:V1.2
CLK1:TRIGGER: CLK1:C1.1, CLK1:IC5.2, CLK1:IC5.6, CLK1:R7.3
CLR: ALU1:IC5.15, A_REGISTER1:IC2.15, A_REGISTER1:IC3.15, B_REGISTER1:IC2.15, B_REGISTER1:IC3.15, CONTROL_LOGIC1:IC5.8, INST_REGISTER1:IC2.15, INST_REGISTER1:IC3.15, JP13.1, JP14.2, JP16.2, JP20.2, PROGRAM-COUNTER1:IC1.15, PROGRAM-COUNTER1:IC2.15, PROGRAM-COUNTER1:IC4.15, PROGRAM-COUNTER1:IC5.15, RAM1:IC2.15, RAM1:IC3.15, RAM1:IC12.15, RAM1:IC13.15, SV25.2
CONTROL_LOGIC1:N$1: CONTROL_LOGIC1:IC1.19, CONTROL_LOGIC1:IC2.19, CONTROL_LOGIC1:IC3.1, CONTROL_LOGIC1:V1.12
CONTROL_LOGIC1:N$2: CONTROL_LOGIC1:IC1.22, CONTROL_LOGIC1:IC2.22, CONTROL_LOGIC1:IC3.2, CONTROL_LOGIC1:V1.13
CONTROL_LOGIC1:N$3: CONTROL_LOGIC1:IC1.23, CONTROL_LOGIC1:IC2.23, CONTROL_LOGIC1:IC3.3, CONTROL_LOGIC1:V1.14
CONTROL_LOGIC1:N$4: CONTROL_LOGIC1:IC3.10, CONTROL_LOGIC1:IC5.2
CONTROL_LOGIC1:N$5: CONTROL_LOGIC1:IC3.15, CONTROL_LOGIC1:LED9.A
CONTROL_LOGIC1:N$6: CONTROL_LOGIC1:IC3.14, CONTROL_LOGIC1:LED10.A
CONTROL_LOGIC1:N$7: CONTROL_LOGIC1:IC5.3, CONTROL_LOGIC1:IC5.12, CONTROL_LOGIC1:IC5.13
CONTROL_LOGIC1:N$8: CONTROL_LOGIC1:IC5.11, CONTROL_LOGIC1:V1.1
CONTROL_LOGIC1:N$9: CONTROL_LOGIC1:IC3.13, CONTROL_LOGIC1:LED11.A
CONTROL_LOGIC1:N$10: CONTROL_LOGIC1:IC3.12, CONTROL_LOGIC1:LED12.A
CONTROL_LOGIC1:N$11: CONTROL_LOGIC1:IC3.11, CONTROL_LOGIC1:LED13.A
CONTROL_LOGIC1:N$12: CONTROL_LOGIC1:LED6.K, CONTROL_LOGIC1:R9.2
CONTROL_LOGIC1:N$13: CONTROL_LOGIC1:LED7.K, CONTROL_LOGIC1:R10.2
CONTROL_LOGIC1:N$14: CONTROL_LOGIC1:LED8.K, CONTROL_LOGIC1:R11.2
CONTROL_LOGIC1:N$15: CONTROL_LOGIC1:LED17.K, CONTROL_LOGIC1:R12.2
CONTROL_LOGIC1:N$16: CONTROL_LOGIC1:LED18.K, CONTROL_LOGIC1:R13.2
CONTROL_LOGIC1:N$17: CONTROL_LOGIC1:LED19.K, CONTROL_LOGIC1:R14.2
CONTROL_LOGIC1:N$18: CONTROL_LOGIC1:LED20.K, CONTROL_LOGIC1:R15.2
CONTROL_LOGIC1:N$19: CONTROL_LOGIC1:LED21.K, CONTROL_LOGIC1:R16.2
CONTROL_LOGIC1:N$20: CONTROL_LOGIC1:LED1.K, CONTROL_LOGIC1:R1.2
CONTROL_LOGIC1:N$21: CONTROL_LOGIC1:LED2.K, CONTROL_LOGIC1:R2.2
CONTROL_LOGIC1:N$22: CONTROL_LOGIC1:LED3.K, CONTROL_LOGIC1:R3.2
CONTROL_LOGIC1:N$23: CONTROL_LOGIC1:LED4.K, CONTROL_LOGIC1:R4.2
CONTROL_LOGIC1:N$24: CONTROL_LOGIC1:LED5.K, CONTROL_LOGIC1:R5.2
CONTROL_LOGIC1:N$25: CONTROL_LOGIC1:LED14.K, CONTROL_LOGIC1:R6.2
CONTROL_LOGIC1:N$26: CONTROL_LOGIC1:LED15.K, CONTROL_LOGIC1:R7.2
CONTROL_LOGIC1:N$27: CONTROL_LOGIC1:IC5.4, CONTROL_LOGIC1:IC5.5, CONTROL_LOGIC1:R22.2, CONTROL_LOGIC1:S1.1B
CONTROL_LOGIC1:N$28: CONTROL_LOGIC1:LED16.K, CONTROL_LOGIC1:R8.2
CONTROL_LOGIC1:N$29: CONTROL_LOGIC1:LED9.K, CONTROL_LOGIC1:R17.2
CONTROL_LOGIC1:N$30: CONTROL_LOGIC1:LED10.K, CONTROL_LOGIC1:R18.2
CONTROL_LOGIC1:N$31: CONTROL_LOGIC1:LED11.K, CONTROL_LOGIC1:R19.2
CONTROL_LOGIC1:N$32: CONTROL_LOGIC1:LED12.K, CONTROL_LOGIC1:R20.2
CONTROL_LOGIC1:N$33: CONTROL_LOGIC1:LED13.K, CONTROL_LOGIC1:R21.2
COUNT: CONTROL_LOGIC1:IC2.14, CONTROL_LOGIC1:LED17.A, PROGRAM-COUNTER1:V1.7, PROGRAM-COUNTER1:V1.10, PROGRAM-COUNTER1:V2.7, PROGRAM-COUNTER1:V2.10, PROGRAM-COUNTER1:V3.7, PROGRAM-COUNTER1:V3.10, PROGRAM-COUNTER1:V4.7, PROGRAM-COUNTER1:V4.10, SV23.5, SV26.3
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

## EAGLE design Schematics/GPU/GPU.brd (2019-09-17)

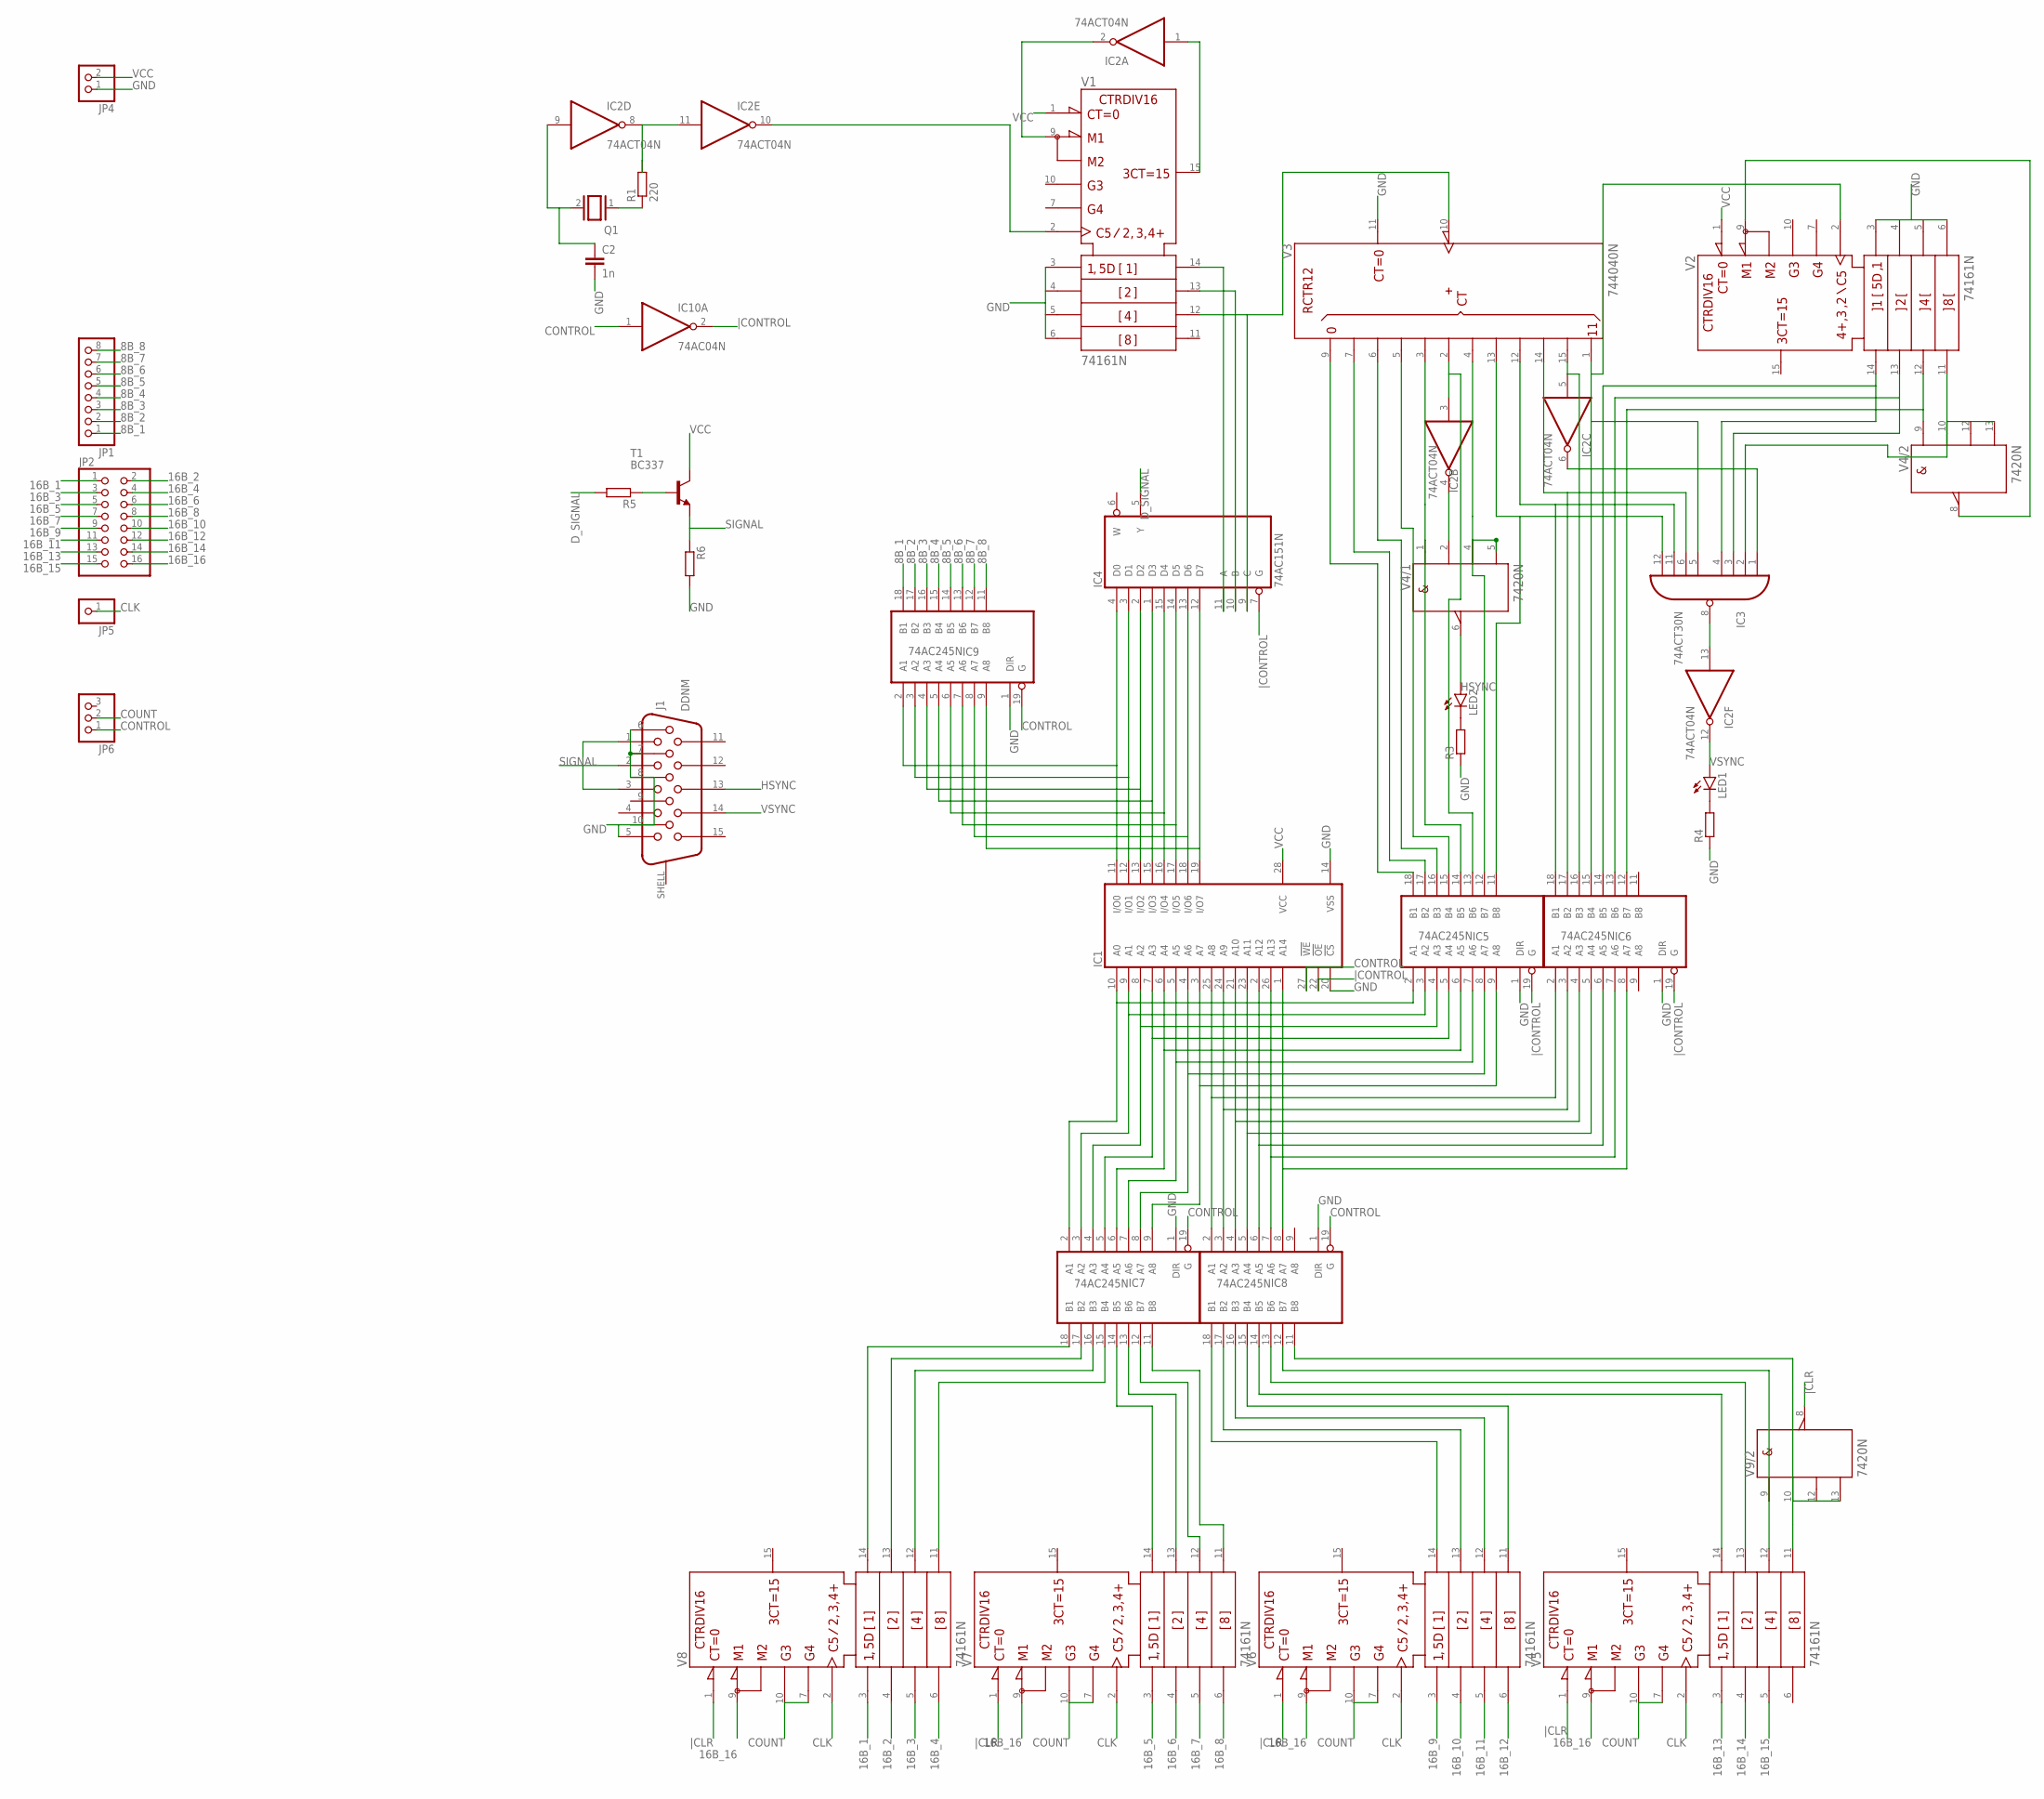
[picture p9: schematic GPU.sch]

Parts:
C2: 1n; C025-025X050
IC1: 62256P; DIL28-6
IC2: 74ACT04N; DIL14
IC3: 74ACT30N; DIL14
IC4: 74AC151N; DIL16
IC5, IC6, IC7, IC8, IC9: 74AC245N; DIL20
IC10: 74AC04N; DIL14
J1: DDNM; DNM
JP1: PINHD-1X8; 1X08
JP2: PINHD-2X8; 2X08
JP4: PINHD-1X2; 1X02
JP5: PINHD-1X1; 1X01
JP6: PINHD-1X3; 1X03
LED1, LED2: LED5MM
Q1: XTAL/S; QS
R1: 220; 0204/7
R3, R4, R5, R6: R-EU_0204/7; 0204/7
T1: BC337; TO92
V1, V2, V5, V6, V7, V8: 74161N; DIL16
V3: 744040N; DIL16
V4, V9: 7420N; DIL14

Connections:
8B_1: IC9.18 (B1), JP1.1
8B_2: IC9.17 (B2), JP1.2
8B_3: IC9.16 (B3), JP1.3
8B_4: IC9.15 (B4), JP1.4
8B_5: IC9.14 (B5), JP1.5
8B_6: IC9.13 (B6), JP1.6
8B_7: IC9.12 (B7), JP1.7
8B_8: IC9.11 (B8), JP1.8
16B_1: JP2.1, V8.3 (A)
16B_2: JP2.2, V8.4 (B)
16B_3: JP2.3, V8.5 (C)
16B_4: JP2.4, V8.6 (D)
16B_5: JP2.5, V7.3 (A)
16B_6: JP2.6, V7.4 (B)
16B_7: JP2.7, V7.5 (C)
16B_8: JP2.8, V7.6 (D)
16B_9: JP2.9, V6.3 (A)
16B_10: JP2.10, V6.4 (B)
16B_11: JP2.11, V6.5 (C)
16B_12: JP2.12, V6.6 (D)
16B_13: JP2.13, V5.3 (A)
16B_14: JP2.14, V5.4 (B)
16B_15: JP2.15, V5.5 (C)
16B_16: JP2.16, V5.9 (!LOAD), V6.9 (!LOAD), V7.9 (!LOAD), V8.9 (!LOAD)
+UB: V1.16 (+UB), V2.16 (+UB), V3.16 (+UB), V4.14 (+UB), V5.16 (+UB), V6.16 (+UB), V7.16 (+UB), V8.16 (+UB), V9.14 (+UB)
-UB: V1.8 (-UB), V2.8 (-UB), V3.8 (-UB), V4.7 (-UB), V5.8 (-UB), V6.8 (-UB), V7.8 (-UB), V8.8 (-UB), V9.7 (-UB)
CLK: JP5.1, V5.2 (CLK), V6.2 (CLK), V7.2 (CLK), V8.2 (CLK)
CONTROL: IC1.27 (!WE), IC7.19 (G), IC8.19 (G), IC9.19 (G), IC10.1 (I), JP6.1
COUNT: JP6.2, V5.7 (ENP), V5.10 (ENT), V6.7 (ENP), V6.10 (ENT), V7.7 (ENP), V7.10 (ENT), V8.7 (ENP), V8.10 (ENT)
D_SIGNAL: IC4.5 (Y), R5.2
GND: C2.2, IC1.14 (VSS), IC1.20 (!CS), IC2.7 (GND), IC3.7 (GND), IC4.8 (GND), IC5.1 (DIR), IC5.10 (GND), IC6.1 (DIR), IC6.10 (GND), IC7.1 (DIR), IC7.10 (GND), IC8.1 (DIR), IC8.10 (GND), IC9.1 (DIR), IC9.10 (GND), IC10.7 (GND), J1.5, J1.6, J1.7, J1.8, J1.10, JP4.1, R3.1, R4.1, R6.2, V1.3 (A), V1.4 (B), V1.5 (C), V1.6 (D), V2.3 (A), V2.4 (B), V2.5 (C), V2.6 (D), V3.11 (CLR)
HSYNC: J1.13, LED2.A, V4.6 (Y)
unnamed: C2.1, IC2.9 (I), Q1.2
unnamed: Q1.1, R1.1
unnamed: IC2.10 (O), V1.2 (CLK)
unnamed: IC2.2 (O), V1.9 (!LOAD)
unnamed: IC4.9 (C), V1.12 (QC), V3.10 (CLK)
unnamed: IC2.1 (I), V1.15 (RCO)
unnamed: IC5.18 (B1), V3.9 (QA)
unnamed: IC5.17 (B2), V3.7 (QB)
unnamed: IC5.14 (B5), V3.3 (QE), V4.1 (A)
unnamed: IC5.12 (B7), V3.4 (QG), V4.4 (C), V4.5 (D)
unnamed: IC3.5 (I4), IC6.15 (B4), V2.2 (CLK), V3.1 (QL)
unnamed: IC3.12 (I7), IC5.11 (B8), V3.13 (QH)
unnamed: V2.9 (!LOAD), V4.8 (Y)
unnamed: IC1.10 (A0), IC5.2 (A1), IC7.2 (A1)
unnamed: IC3.2 (I1), V2.11 (QD), V4.10 (B), V4.12 (C), V4.13 (D)
unnamed: IC3.11 (I6), IC6.18 (B1), V3.12 (QI)
unnamed: IC3.6 (I5), IC6.17 (B2), V3.14 (QJ)
unnamed: IC3.4 (I3), IC6.14 (B5), V2.14 (QA)
unnamed: IC3.3 (I2), IC6.13 (B6), V2.13 (QB)
unnamed: IC2.5 (I), IC6.16 (B3), V3.15 (QK)
unnamed: IC2.6 (O), IC3.1 (I0)
unnamed: IC2.13 (I), IC3.8 (O)
unnamed: IC4.11 (A), V1.14 (QA)
unnamed: IC4.10 (B), V1.13 (QB)
unnamed: IC5.16 (B3), V3.6 (QC)
unnamed: R5.1, T1.2 (B)
unnamed: LED2.K (C), R3.2
unnamed: LED1.K (C), R4.2
unnamed: IC2.8 (O), IC2.11 (I), R1.2
unnamed: IC5.15 (B4), V3.5 (QD)
unnamed: IC1.9 (A1), IC5.3 (A2), IC7.3 (A2)
unnamed: IC1.8 (A2), IC5.4 (A3), IC7.4 (A3)
unnamed: IC1.7 (A3), IC5.5 (A4), IC7.5 (A4)
unnamed: IC2.4 (O), V4.2 (B)
unnamed: IC1.6 (A4), IC5.6 (A5), IC7.6 (A5)
unnamed: IC6.12 (B7), V2.12 (QC), V4.9 (A)
unnamed: IC1.5 (A5), IC5.7 (A6), IC7.7 (A6)
unnamed: IC1.4 (A6), IC5.8 (A7), IC7.8 (A7)
unnamed: IC2.3 (I), IC5.13 (B6), V3.2 (QF)
unnamed: IC1.3 (A7), IC5.9 (A8), IC7.9 (A8)
unnamed: IC1.25 (A8), IC6.2 (A1), IC8.2 (A1)
unnamed: IC1.24 (A9), IC6.3 (A2), IC8.3 (A2)
unnamed: IC1.21 (A10), IC6.4 (A3), IC8.4 (A3)
unnamed: IC1.23 (A11), IC6.5 (A4), IC8.5 (A4)
unnamed: IC1.2 (A12), IC6.6 (A5), IC8.6 (A5)
unnamed: IC1.26 (A13), IC6.7 (A6), IC8.7 (A6)
unnamed: IC1.1 (A14), IC6.8 (A7), IC8.8 (A7)
unnamed: IC8.12 (B7), V5.12 (QC), V9.9 (A)
unnamed: IC8.11 (B8), V5.11 (QD), V9.10 (B), V9.12 (C), V9.13 (D)
unnamed: IC7.18 (B1), V8.14 (QA)
unnamed: IC7.17 (B2), V8.13 (QB)
unnamed: IC7.16 (B3), V8.12 (QC)
unnamed: IC7.15 (B4), V8.11 (QD)
unnamed: IC7.14 (B5), V7.14 (QA)
unnamed: IC7.13 (B6), V7.13 (QB)
unnamed: IC7.12 (B7), V7.12 (QC)
unnamed: IC7.11 (B8), V7.11 (QD)
unnamed: IC8.18 (B1), V6.14 (QA)
unnamed: IC8.13 (B6), V5.13 (QB)
unnamed: IC8.14 (B5), V5.14 (QA)
unnamed: IC8.15 (B4), V6.11 (QD)
unnamed: IC8.16 (B3), V6.12 (QC)
unnamed: IC8.17 (B2), V6.13 (QB)
unnamed: IC1.19 (I/O7), IC4.12 (D7), IC9.9 (A8)
unnamed: IC1.17 (I/O5), IC4.14 (D5), IC9.7 (A6)
unnamed: IC1.18 (I/O6), IC4.13 (D6), IC9.8 (A7)
unnamed: IC1.16 (I/O4), IC4.15 (D4), IC9.6 (A5)
unnamed: IC1.15 (I/O3), IC4.1 (D3), IC9.5 (A4)
unnamed: IC1.13 (I/O2), IC4.2 (D2), IC9.4 (A3)
unnamed: IC1.12 (I/O1), IC4.3 (D1), IC9.3 (A2)
unnamed: IC1.11 (I/O0), IC4.4 (D0), IC9.2 (A1)
SIGNAL: J1.1, J1.2, J1.3, R6.1, T1.1 (E)
VCC: IC1.28 (VCC), IC2.14 (VCC), IC3.14 (VCC), IC4.16 (VCC), IC5.20 (VCC), IC6.20 (VCC), IC7.20 (VCC), IC8.20 (VCC), IC9.20 (VCC), IC10.14 (VCC), JP4.2, T1.3 (C), V1.1 (!CLR), V2.1 (!CLR)
VSYNC: IC2.12 (O), J1.14, LED1.A
|CLR: V5.1 (!CLR), V6.1 (!CLR), V7.1 (!CLR), V8.1 (!CLR), V9.8 (Y)
|CONTROL: IC1.22 (!OE), IC4.7 (G), IC5.19 (G), IC6.19 (G), IC10.2 (O)

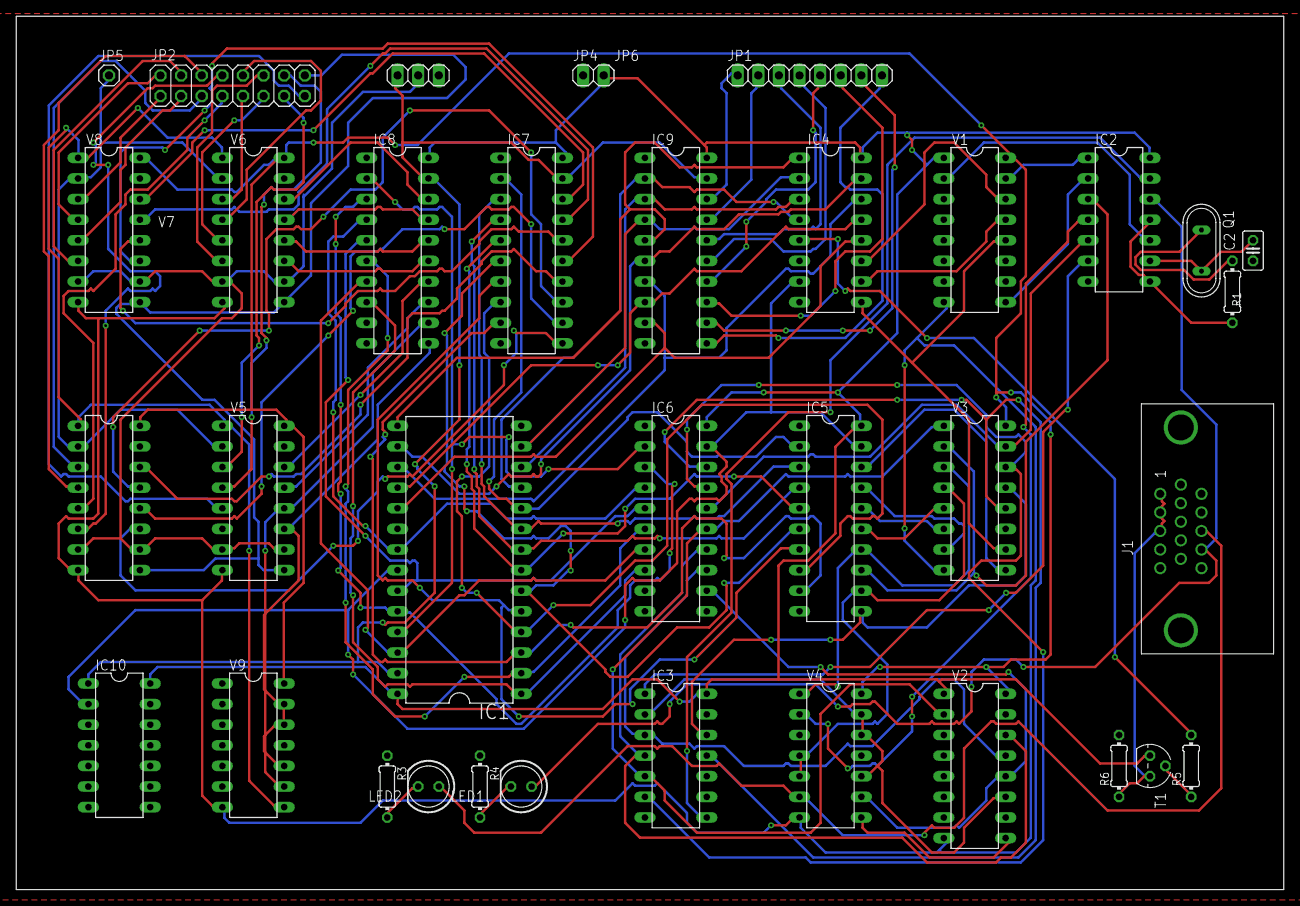
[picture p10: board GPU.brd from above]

Board: 2 copper layers, 156.2 x 107.6 mm, 35 parts (0 on the bottom side), 108 nets.

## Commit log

2019-04-27 Started Eagle Drawings
    [Proto.sch]
2019-04-28 Some Modules Added
    Ram, Pc, A and B registers and ALU added.
    [Proto.sch]
2019-04-30 Schematics Are Done
2019-04-30 Some Changes
    [Proto.sch, pc.csv]
2019-05-03 All parts connected
    [Proto.sch, proto.brd]
2019-05-04 PCB Design Started
    [Proto.sch]
2019-05-06 PCB Made Better
    [Proto.sch, pc.csv, proto.brd]
2019-05-09 Board Edited
    [Proto.sch, proto.brd]
2019-05-09 Small Fix
    [proto.brd]
2019-05-10 Added renderings and autoroute schematics
    [Proto.sch, proto.brd]
2019-05-10 3D Design Updated
    [Proto.sch, proto.brd]
2019-07-09 Boards Divided and Gpu Work Started
    [ALU.brd, Clock_BUS.brd, GPU.sch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]
2019-07-11 Routd and Cams Created
    [ALU.brd, Clock_BUS.brd, Control_Logic.brd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]
2019-07-11 Design İmproved
    [GPU.sch]
2019-07-12 Visual Improvments
    [ALU.brd, Clock_BUS.brd, Control_Logic.brd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]
2019-08-19 Microcode Added and Ram Updated
    [ALU.brd, Clock_BUS.brd, Control_Logic.brd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]
2019-08-19 Gpu Updated
    [copper_bottom.gbr, copper_top.gbr, drills.xln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]
2019-09-17 Bin Added and Sch Fixed
    [GPU.brd, GPU.sch, proto.brd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]
